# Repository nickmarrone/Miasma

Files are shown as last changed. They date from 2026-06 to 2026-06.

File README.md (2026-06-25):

# Miasma 1.04 Revised

***Note: use the BOM included in this repository.*** Some of the components have been relabelled in this revision so the BOM on SinPhi's website is no longer current.

The changes from version 1.03 are:

1) Updated the footprints and symbols to ones included in KiCAD 5.1.5, or otherwise included the auxillary libraries in the repository.

2) Made the 4QX output no longer inverted and added a jumper pin on the back that allows you to switch between (non-inverted) summing and 4QX modes.

3) Added diodes and jumper pins between the cycle gate input and trigger switch for each side. This allows you to choose whether applying a gate to the cycle input will cause it to start cycling automatically (jumper on) or require a trigger to start cycling (jumper off).

4) Fixed the EOC2 output from not being grounded.

5) Small tweaks such as adjusting track spacing, etc.

To do: the resistor in the feedback loop of the 4QX output amp (R67) should be shorted (solder bridge), not 220k. The purpose is to make this output stage a unity gain buffer instead of an amplifier; the 220k will cause the output to clip before the signal peak is reached. If you aren't using the 4QX feature then this is irrelevant.

# 1.04 Revision

Improve silkscreen placement of component labels for legibility. Upgrade kicad project files to v10.

# Acknowledgements

Original Miasma board by Sin Phi http://www.sinphi.com/synths/miasma/miasma.html, based on the Befaco Rampage http://www.befaco.org/rampage-2/. 4QX and diode mods inspired by Mcop http://www.mcop.co.uk/diy/mods-and-stripboard-layouts/miasma-function-generator-modifications/.

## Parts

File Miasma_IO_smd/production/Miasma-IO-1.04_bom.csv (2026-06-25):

Designator | Footprint | Quantity | Value | LCSC Part #
4QX1, CYCLE1, CYCLE2, EOC1, EOC2, EXPCV1, EXPCV2, FALL1, FALL2, FALLCV1, FALLCV2, IN1, IN2, LGTR1, MAX1, MIN1, OUT1, OUT2, RISE1, RISE2, RISECV1, RISECV2, TRIG1, TRIG2 | WQP-PJ301M-12_JACK | 24 | Thonk
BALANCE1 | Potentiometer_Alpha_RD901F-40-00D_Single_Vertical | 1 | 1M
C1, C11, C14, C4 | C_0805_HandSoldering | 4 | 10n
C10, C8 | C_0805_HandSoldering | 2 | 100nF
C12, C2 | C_0805_HandSoldering | 2 | 470n
C13, C3 | C_0805_HandSoldering | 2 | 47n
C6, C9 | C_0805_HandSoldering | 2 | 100n
CYCLESW1, CYCLESW2, RANGESW1, RANGESW2, TRIGGERSW1 | SPDT_Switch_P4.7mm | 5 | SWITCH_INV
D1, D2, D3, D4, D5, D6 | D_SOD-323_HandSoldering | 6 | 1N4148WS
FALLCVPOT1, FALLCVPOT2, FALLPOT1, FALLPOT2, RISECVPOT1, RISECVPOT2, RISEPOT1, RISEPOT2 | Potentiometer_Alpha_RD901F-40-00D_Single_Vertical | 8 | 100k
FALLTRIM1, FALLTRIM2, RISETRIM1, RISETRIM2 | Bourns_3362P | 4 | 100k
LEDF1, LEDF2, LEDR1, LEDR2 | LED-3MM | 4 | LED
P1, P4 | PinHeader_1x12_P2.54mm_Vertical | 2 | CONN_01X12
P2, P3 | PinHeader_1x10_P2.54mm_Vertical | 2 | CONN_01X10
P5, P6 | PinSocket_1x02_P2.54mm_Vertical | 2 | Conn_01x02
Q1, Q2, Q3, Q4 | SOT-23_Handsoldering | 4 | MMBT3904
R1, R27, R3, R33, R4, R53, R54, R56 | R_0805_HandSoldering | 8 | 10k
R10, R11, R12, R2, R21, R22, R38, R42, R46, R49, R51, R55 | R_0805_HandSoldering | 12 | 100k
R13, R35, R45, R6 | R_0805_HandSoldering | 4 | 47k
R14, R15, R16, R23, R24, R25, R26, R30, R31, R32, R34, R39, R40, R41 | R_0805_HandSoldering | 14 | 1k
R17, R36, R47, R57, R7 | R_0805_HandSoldering | 5 | 1M
R18, R37, R48, R8 | R_0805_HandSoldering | 4 | 110k
R19, R20, R43, R44 | R_0805_HandSoldering | 4 | 2k2
R28, R29 | R_0805_HandSoldering | 2 | 4M7
R5, R50, R52, R9 | R_0805_HandSoldering | 4 | 23k7
SHAPE1, SHAPE2 | Potentiometer_Alpha_RD902F-40-00D_Dual_Vertical | 2 | 10K
SYMETRY1, SYMETRY2 | Bourns_3362P | 2 | 10k
U1 | SOIC-14_3.9x8.7mm_P1.27mm | 1 | TL074

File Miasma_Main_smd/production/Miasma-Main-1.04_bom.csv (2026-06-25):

Designator | Footprint | Quantity | Value | LCSC Part #
C1, C2 | 0805 | 2 | 560p
C10, C11, C12, C13, C14, C15, C16, C17, C19, C20, C21, C22, C23, C24, C25, C26, C27, C28, C5, C6 | 0805 | 20 | 100n
C18, C9 | c_elec_6.3x5.8 | 2 | 10u
C29, C30 | 0805 | 2 | 1n
C3, C4 | 0805 | 2 | 100p
C7, C8 | C_Rect_L7.2mm_W4.5mm_P5.00mm_FKS2_FKP2_MKS2_MKP2 | 2 | 2n2 (PP)
D1, D2 | D_SOD-123 | 2 | 1N5819HW
D10, D11, D12, D13, D14, D15, D16, D17, D18, D19, D20, D21, D22, D23, D24, D25, D3, D4, D5, D6, D7, D8, D9 | D_SOD-323_HandSoldering | 23 | 1N4148WS
P1, P3 | PinHeader_1x12_P2.54mm_Vertical | 2 | CONN_01X12
P2, P4 | PinHeader_1x10_P2.54mm_Vertical | 2 | CONN_01X10
P5 | PinHeader_2x05_P2.54mm_Vertical | 1 | CONN_02X05
P6 | MountingHole_2.7mm_M2.5_DIN965_Pad | 1 | CONN_01X01
P7 | PinHeader_1x03_P2.54mm_Vertical | 1 | SUM_or_4QX
Q1, Q2, Q3, Q4 | SOT-23_Handsoldering | 4 | MMBT3904
R1, R2, R40, R41 | 0805 | 4 | 30k
R10, R14, R16, R8 | 0805 | 4 | 3M
R11, R13, R17, R24, R25, R7 | 0805 | 6 | 560k
R12, R26, R27, R28, R29, R30, R31, R32, R33, R34, R35, R46, R47, R48, R49, R50, R51, R52, R53, R54, R55, R56, R57, R6, R60, R78, R79, R83, R90, R91 | 0805 | 30 | 100k
R15, R18, R19, R74, R76, R9 | 0805 | 6 | 1M
R20, R22, R36, R38 | 0805 | 4 | 4k7
R21, R23, R37, R39, R4, R42, R43, R44, R45, R5, R58, R59, R64, R66, R86, R89 | 0805 | 16 | 10k
R3 | 0805 | 1 | 10M
R61, R62, R80, R81 | 0805 | 4 | 110k
R63, R65 | 0805 | 2 | 180k
R67 | 0805 | 1 | 220k
R68, R69, R70, R71 | 0805 | 4 | 2k2
R72, R73 | 0805 | 2 | 470k
R75, R77 | 0805 | 2 | 22k
R82 | 0805 | 1 | 20k
R84, R85, R87, R88 | 0805 | 4 | 1k
T1, T3 | TSOT-23-6_HandSoldering | 2 | BCM857DS
T2, T4 | TSOT-23-6_HandSoldering | 2 | BCM847DS
U1, U2, U3, U4, U5, U6, U7, U8 | SOIC-14_3.9x8.7mm_P1.27mm | 8 | TL074
U9 | SOIC-8_3.9x4.9mm_P1.27mm | 1 | AD633

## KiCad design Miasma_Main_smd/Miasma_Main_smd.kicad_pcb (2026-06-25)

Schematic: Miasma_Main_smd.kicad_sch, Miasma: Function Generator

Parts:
C1, C2: 560p; C_0805_2012Metric_Pad1.15x1.40mm_HandSolder
C3, C4: 100p; C_0805_2012Metric_Pad1.15x1.40mm_HandSolder
C5, C6, C10, C11, C12, C13, C14, C15, C16, C17, C19, C20, C21, C22, C23, C24, C25, C26, C27, C28: 100n; C_0805_2012Metric_Pad1.15x1.40mm_HandSolder
C9, C18: 10u; c_elec_6.3x5.8
C29, C30: 1n; C_0805_2012Metric_Pad1.15x1.40mm_HandSolder
D1, D2: 1N5819HW; D_SOD-123
D3, D4, D5, D6, D7, D8, D9, D10, D11, D12, D13, D14, D15, D16, D17, D18, D19, D20, D21, D22, D23, D24, D25: 1N4148WS; D_SOD-323_HandSoldering
P1, P3: CONN_01X12; PinHeader_1x12_P2.54mm_Vertical
P2, P4: CONN_01X10; PinHeader_1x10_P2.54mm_Vertical
P5: CONN_02X05; PinHeader_2x05_P2.54mm_Vertical
P6: CONN_01X01; MountingHole_2.7mm_M2.5_DIN965_Pad
P7: SUM_or_4QX; PinHeader_1x03_P2.54mm_Vertical
Q1, Q2, Q3, Q4: MMBT3904; SOT-23_Handsoldering
R1, R2, R40, R41: 30k; R_0805_2012Metric_Pad1.15x1.40mm_HandSolder
R3: 10M; R_0805_2012Metric_Pad1.15x1.40mm_HandSolder
R4, R5, R21, R23, R37, R39, R42, R43, R44, R45, R58, R59, R64, R66, R86, R89: 10k; R_0805_2012Metric_Pad1.15x1.40mm_HandSolder
R6, R12, R26, R27, R28, R29, R30, R31, R32, R33, R34, R35, R46, R47, R48, R49, R50, R51, R52, R53, R54, R55, R56, R57, R60, R78, R79, R83, R90, R91: 100k; R_0805_2012Metric_Pad1.15x1.40mm_HandSolder
R7, R11, R13, R17, R24, R25: 560k; R_0805_2012Metric_Pad1.15x1.40mm_HandSolder
R8, R10, R14, R16: 3M; R_0805_2012Metric_Pad1.15x1.40mm_HandSolder
R9, R15, R18, R19, R74, R76: 1M; R_0805_2012Metric_Pad1.15x1.40mm_HandSolder
R20, R22, R36, R38: 4k7; R_0805_2012Metric_Pad1.15x1.40mm_HandSolder
R61, R62, R80, R81: 110k; R_0805_2012Metric_Pad1.15x1.40mm_HandSolder
R63, R65: 180k; R_0805_2012Metric_Pad1.15x1.40mm_HandSolder
R67: 220k; R_0805_2012Metric_Pad1.15x1.40mm_HandSolder
R68, R69, R70, R71: 2k2; R_0805_2012Metric_Pad1.15x1.40mm_HandSolder
R72, R73: 470k; R_0805_2012Metric_Pad1.15x1.40mm_HandSolder
R75, R77: 22k; R_0805_2012Metric_Pad1.15x1.40mm_HandSolder
R82: 20k; R_0805_2012Metric_Pad1.15x1.40mm_HandSolder
R84, R85, R87, R88: 1k; R_0805_2012Metric_Pad1.15x1.40mm_HandSolder
T1, T3: BCM857DS; TSOT-23-6_HandSoldering
T2, T4: BCM847DS; TSOT-23-6_HandSoldering
U1, U2, U3, U4, U5, U6, U7, U8: TL074; SOIC-14_3.9x8.7mm_P1.27mm
U9: AD633; SOIC-8_3.9x4.9mm_P1.27mm

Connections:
4QX: P4.7, R67.2, U8.8
+1.2V: R86.1, R87.2, U3.9 (-), U6.6 (-)
+2.4V: R82.1, R83.2, U3.2 (-), U6.13 (-)
-1.2V: R88.1, R89.2, U3.12 (+), U6.3 (+)
Bal1: P2.2, R2.2, R90.1, U7.3 (+), U7.5 (+), U8.5 (+), U9.1 (Y1)
Bal2: P4.2, R1.2, R3.2, R91.1, U7.10 (+), U7.12 (+), U8.6 (-), U9.7 (X1)
EOC1: D22.1 (K), P2.9
EOC2: D23.1 (K), P4.9
Exp1: P1.10, R61.2
Exp2: P3.10, R62.2
Fall1: D19.1 (K), P1.2, P2.5
Fall2: D21.1 (K), P3.3, P4.5
FallCv1: P1.4, R10.2, R11.2, R27.1, R28.1, U1.2 (-)
FallCv2: P3.5, R16.2, R17.2, R30.1, R31.1, U4.13 (-)
GND: C9.2, C10.1, C11.1, C12.1, C13.1, C14.1, C15.1, C16.1, C17.1, C18.1, C19.2, C20.2, C21.2, C22.2, C23.2, C24.2, C25.2, C26.2, C27.1, C28.2, P1.1, P1.12, P2.8, P3.1, P3.12, P4.8, P5.3, P5.4, P5.5, P5.6, P5.7, P5.8, Q1.2 (E), Q2.2 (E), Q3.2 (E), Q4.2 (E), R24.2, R25.2, R33.2, R35.2, R40.1, R41.1, R52.2, R53.2, R60.1, R68.1, R69.2, R70.1, R71.2, R75.2, R77.2, R83.1, R84.2, R85.2, R87.1, R88.2, T1.2 (B1), T2.2 (B1), T3.2 (B1), T4.2 (B1), U1.3 (+), U1.10 (+), U1.12 (+), U2.3 (+), U2.10 (+), U2.12 (+), U4.3 (+), U4.5 (+), U4.12 (+), U5.3 (+), U5.5 (+), U5.12 (+), U9.2 (Y2), U9.4 (Z), U9.8 (X2)
In1: D10.1 (K), P2.3, R54.1, U2.6 (-)
In2: D11.1 (K), P4.3, R55.1, U5.9 (-)
L>R: D7.1 (K), P2.7
Max: P4.6, R44.2, U8.14
Min: P2.6, R45.2, U8.1
unnamed: C1.1, R26.2, R27.2, R56.1, U1.8
unnamed: C1.2, R56.2, R61.1, U1.9 (-)
unnamed: C2.1, R29.2, R30.2, R57.1, U4.7
unnamed: C2.2, R57.2, R62.1, U4.6 (-)
unnamed: C3.1, R72.2, T1.3 (C2), T2.6 (C1), U2.13 (-)
unnamed: C3.2, R80.2, U2.14, U3.10 (+), U3.13 (-)
unnamed: C4.1, R73.2, T3.3 (C2), T4.6 (C1), U5.2 (-)
unnamed: C4.2, R81.2, U5.1, U6.2 (-), U6.5 (+)
unnamed: C5.1, D16.2 (A), U3.7
unnamed: C5.2, D22.2 (A), R84.1
unnamed: C6.1, D17.2 (A), U6.8
unnamed: C6.2, D23.2 (A), R85.1
unnamed: D1.2 (A), P5.1, P5.2
unnamed: D2.1 (K), P5.9, P5.10
unnamed: D3.1 (K), D4.1 (K), R18.2, U7.6 (-), U7.9 (-), U8.12 (+)
unnamed: D3.2 (A), U7.7
unnamed: D4.2 (A), U7.8
unnamed: D5.1 (K), U7.1
unnamed: D5.2 (A), D6.2 (A), R19.1, U7.2 (-), U7.13 (-), U8.3 (+)
unnamed: D6.1 (K), U7.14
unnamed: D7.2 (A), U8.7
unnamed: D8.1 (K), R42.1
unnamed: D8.2 (A), U3.1
unnamed: D9.1 (K), R43.1
unnamed: D9.2 (A), U6.14
unnamed: D10.2 (A), Q3.3 (C), R36.1, R37.1
unnamed: D11.2 (A), Q4.3 (C), R38.1, R39.1
unnamed: D12.1 (K), R7.2, R46.2, R68.2, T2.5 (B2)
unnamed: D12.2 (A), D13.2 (A), R9.2
unnamed: D13.1 (K), R47.2, R48.2, R69.1, T1.5 (B2)
unnamed: D14.1 (K), R13.2, R49.2, R70.2, T4.5 (B2)
unnamed: D14.2 (A), D15.2 (A), R15.2
unnamed: D15.1 (K), R50.2, R51.2, R71.1, T3.5 (B2)
unnamed: D16.1 (K), R78.2
unnamed: D17.1 (K), R79.2
unnamed: D18.2 (A), U3.14
unnamed: D19.2 (A), U3.8
unnamed: D20.2 (A), U6.1
unnamed: D21.2 (A), U6.7
unnamed: D24.2 (A), R8.1, R10.1
unnamed: D25.2 (A), R14.1, R16.1
unnamed: P7.1, U9.5 (W)
unnamed: P7.2, U8.10 (+)
unnamed: P7.3, R90.2, R91.2
unnamed: Q1.3 (C), R20.2, R21.2
unnamed: Q2.3 (C), R22.2, R23.2
unnamed: Q3.1 (B), R21.1, R33.1, R42.2
unnamed: Q4.1 (B), R23.1, R35.1, R43.2
unnamed: R4.1, R6.1, R47.1, U1.7
unnamed: R5.1, R12.1, R50.1, U4.8
unnamed: R28.2, R48.1, U1.1
unnamed: R31.2, R51.1, U4.14
unnamed: R32.2, R46.1, U1.14
unnamed: R34.2, R49.1, U4.1
unnamed: R40.2, R44.1, U8.13 (-)
unnamed: R41.2, R45.1, U8.2 (-)
unnamed: R52.1, U2.5 (+)
unnamed: R53.1, U5.10 (+)
unnamed: R54.2, R58.1, U2.7
unnamed: R55.2, R59.1, U5.8
unnamed: R58.2, R63.1, R64.1, U2.2 (-)
unnamed: R59.2, R65.1, R66.1, U5.13 (-)
unnamed: R60.2, R67.1, U8.9 (-)
unnamed: R63.2, R72.1, U2.1
unnamed: R65.2, R73.1, U5.14
unnamed: R74.2, R75.1, R78.1, U3.5 (+)
unnamed: R76.2, R77.1, R79.1, U6.10 (+)
unnamed: R80.1, T1.1 (E1), T1.4 (E2), T2.1 (E1), T2.4 (E2)
unnamed: R81.1, T3.1 (E1), T3.4 (E2), T4.1 (E1), T4.4 (E2)
Out1: C29.2, P2.10, R2.1, R64.2, U2.8, U3.3 (+), U3.6 (-); also elsewhere on the board
Out2: C30.2, P4.10, R1.1, R66.2, U5.7, U6.9 (-), U6.12 (+); also elsewhere on the board
Rise1: D18.1 (K), P1.3, P2.4
Rise2: D20.1 (K), P3.2, P4.4
RiseCv1: P1.5, R6.2, R8.2, R26.1, R32.1, U1.13 (-)
RiseCv2: P3.4, R12.2, R14.2, R29.1, R34.1, U4.2 (-)
RngCap1: C29.1, P1.6, T1.6 (C1), T2.3 (C2), U2.9 (-); also elsewhere on the board
RngCap2: C30.1, P3.6, T3.6 (C1), T4.3 (C2), U5.6 (-); also elsewhere on the board
Sym1_1: P1.7, U1.5 (+)
Sym1_2: P3.7, U4.10 (+)
Sym2_1: D24.1 (K), P1.9, R7.1, R9.1, R11.1
Sym2_2: D25.1 (K), P3.9, R13.1, R15.1, R17.1
Sym3_1: P1.8, R4.2, U1.6 (-)
Sym3_2: P3.8, R5.2, U4.9 (-)
Trig: P3.11, Q2.1 (B), R25.1, R39.2
Trig1: P1.11, Q1.1 (B), R24.1, R37.2
VCC: C9.1, C10.2, C11.2, C12.2, C13.2, C14.2, C15.2, C16.2, C17.2, C27.2, D1.1 (K), P2.1, R19.2, R20.1, R22.1, R36.2, R38.2, R74.1, R76.1, R82.2, R86.2, U1.4 (V+), U2.4 (V+), U3.4 (V+), U4.4 (V+), U5.4 (V+), U6.4 (V+), U7.4 (V+), U8.4 (V+), U9.6 (V+)
VEE: C18.2, C19.1, C20.1, C21.1, C22.1, C23.1, C24.1, C25.1, C26.1, C28.1, D2.2 (A), P4.1, R3.1, R18.1, R89.1, U1.11 (V-), U2.11 (V-), U3.11 (V-), U4.11 (V-), U5.11 (V-), U6.11 (V-), U7.11 (V-), U8.11 (V-), U9.3 (V-)

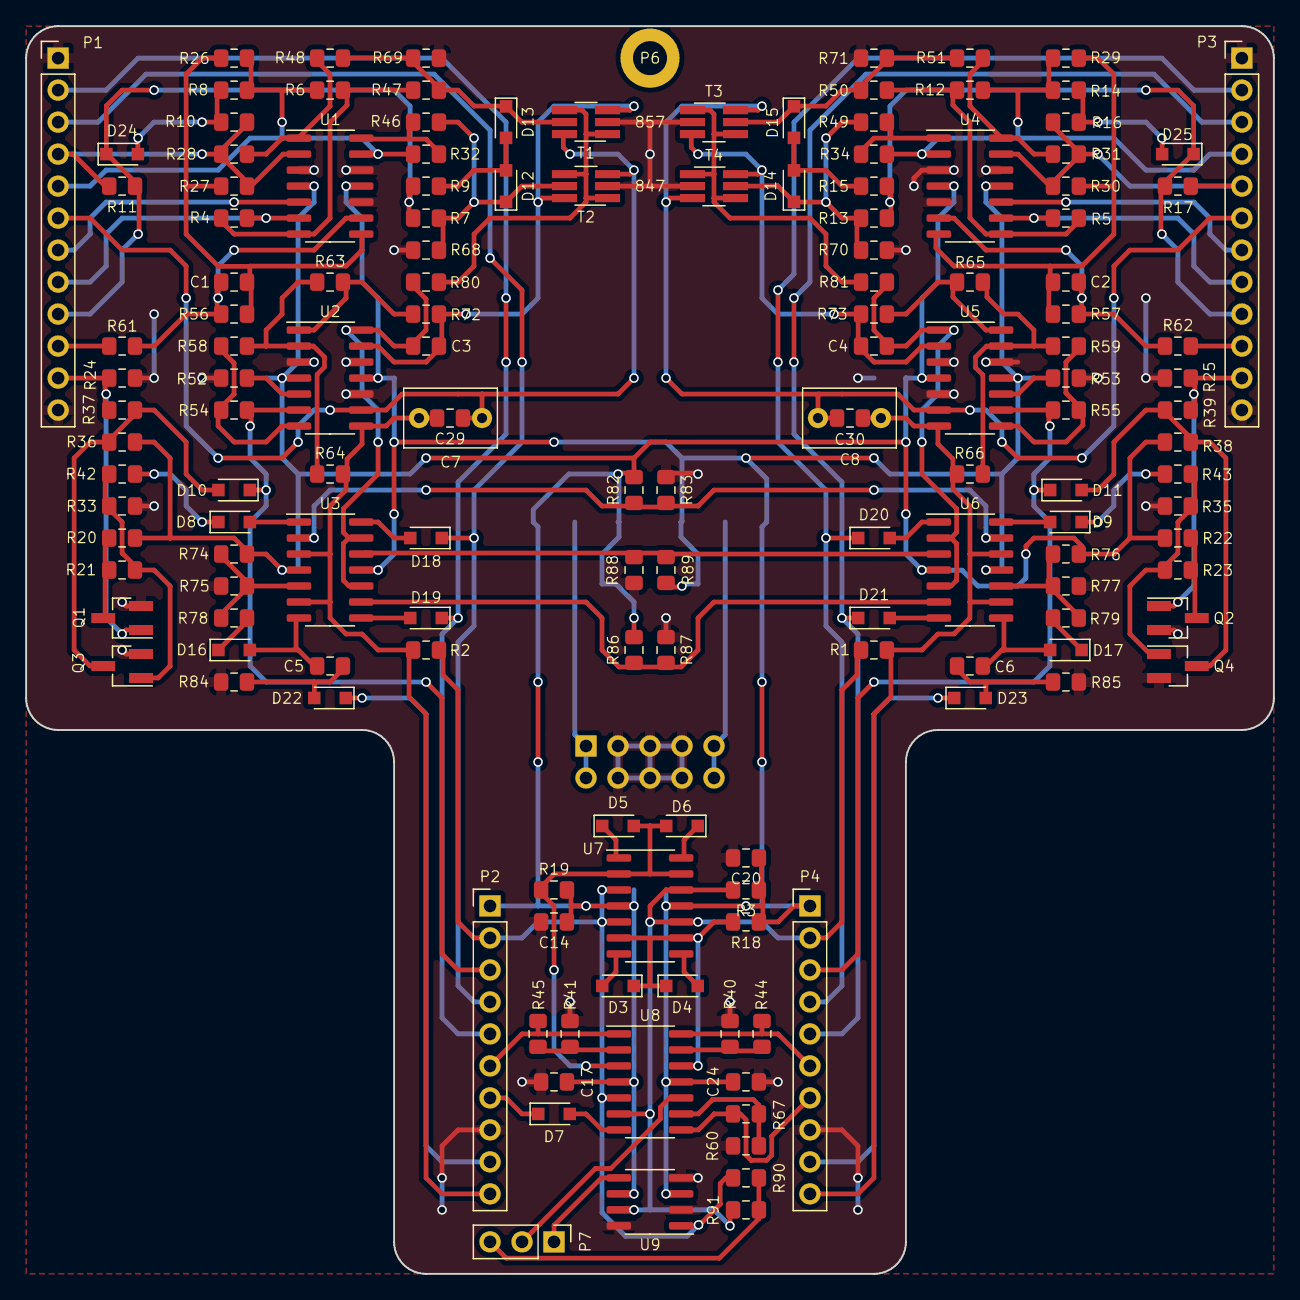
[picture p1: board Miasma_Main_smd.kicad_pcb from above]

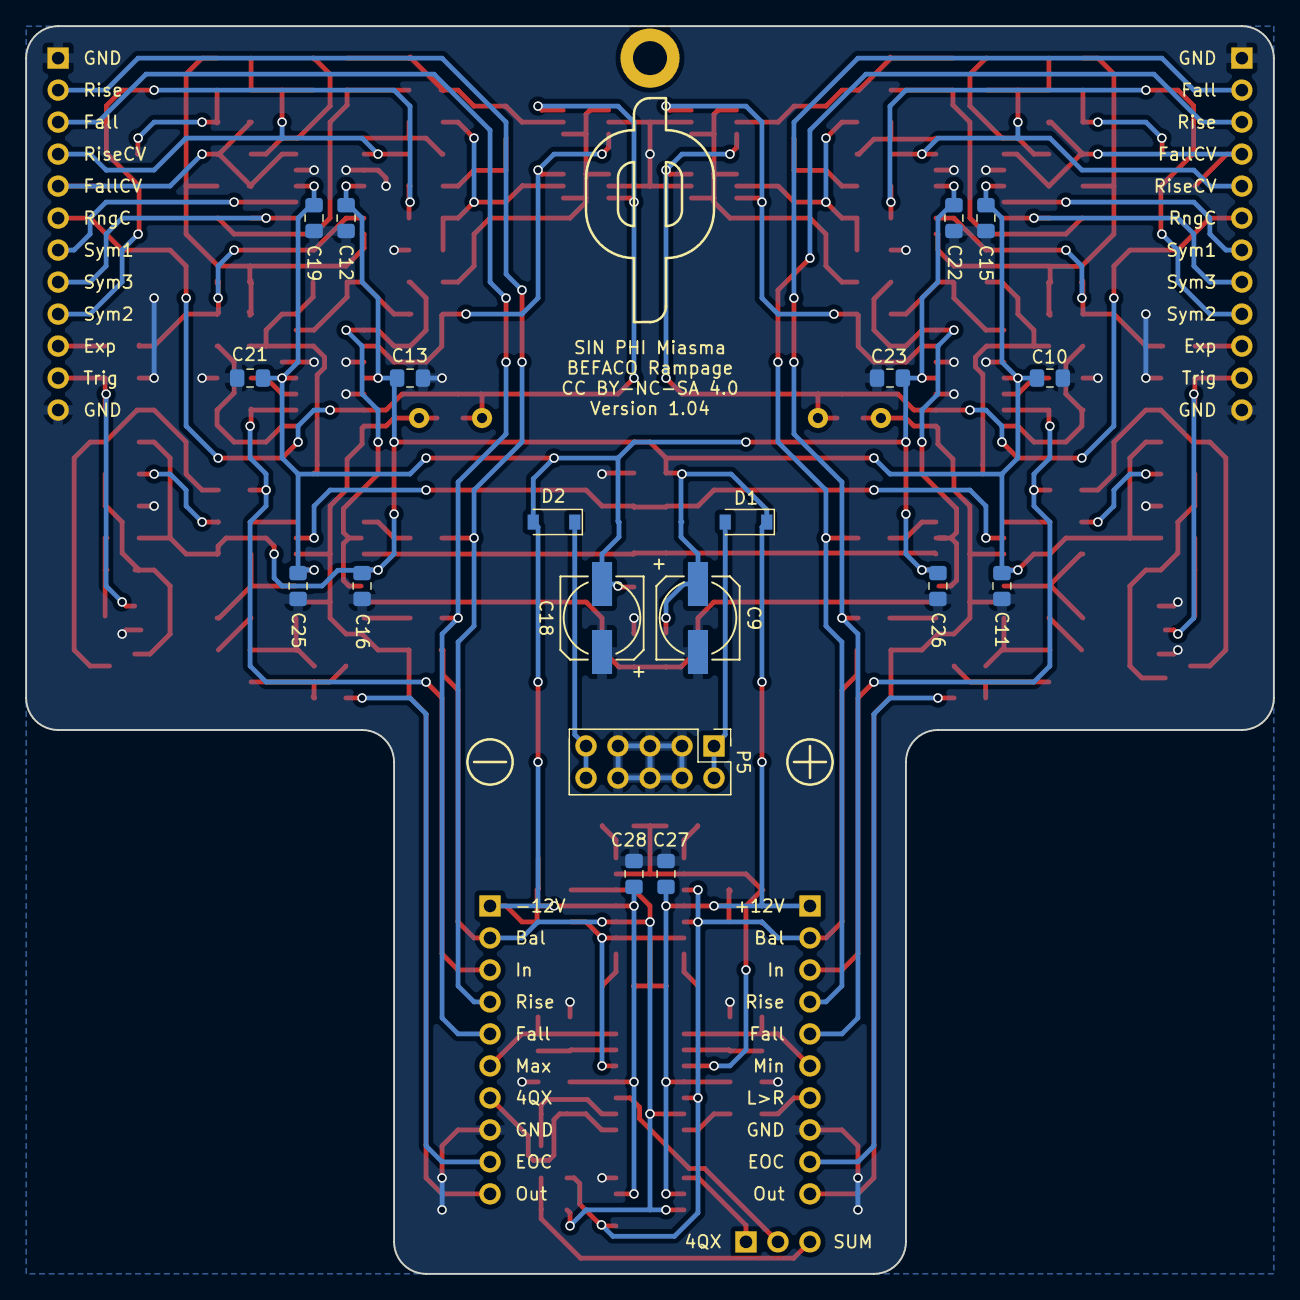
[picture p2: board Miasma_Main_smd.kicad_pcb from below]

Board: 2 copper layers, 99.1 x 99.1 mm, 170 parts (19 on the bottom side), 107 nets.

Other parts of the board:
C7, C8: 2n2 (PP); C_Rect_L7.2mm_W4.5mm_P5.00mm_FKS2_FKP2_MKS2_MKP2

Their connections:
Out1: C7.2; also elsewhere on the board
Out2: C8.2; also elsewhere on the board
RngCap1: C7.1; also elsewhere on the board
RngCap2: C8.1; also elsewhere on the board

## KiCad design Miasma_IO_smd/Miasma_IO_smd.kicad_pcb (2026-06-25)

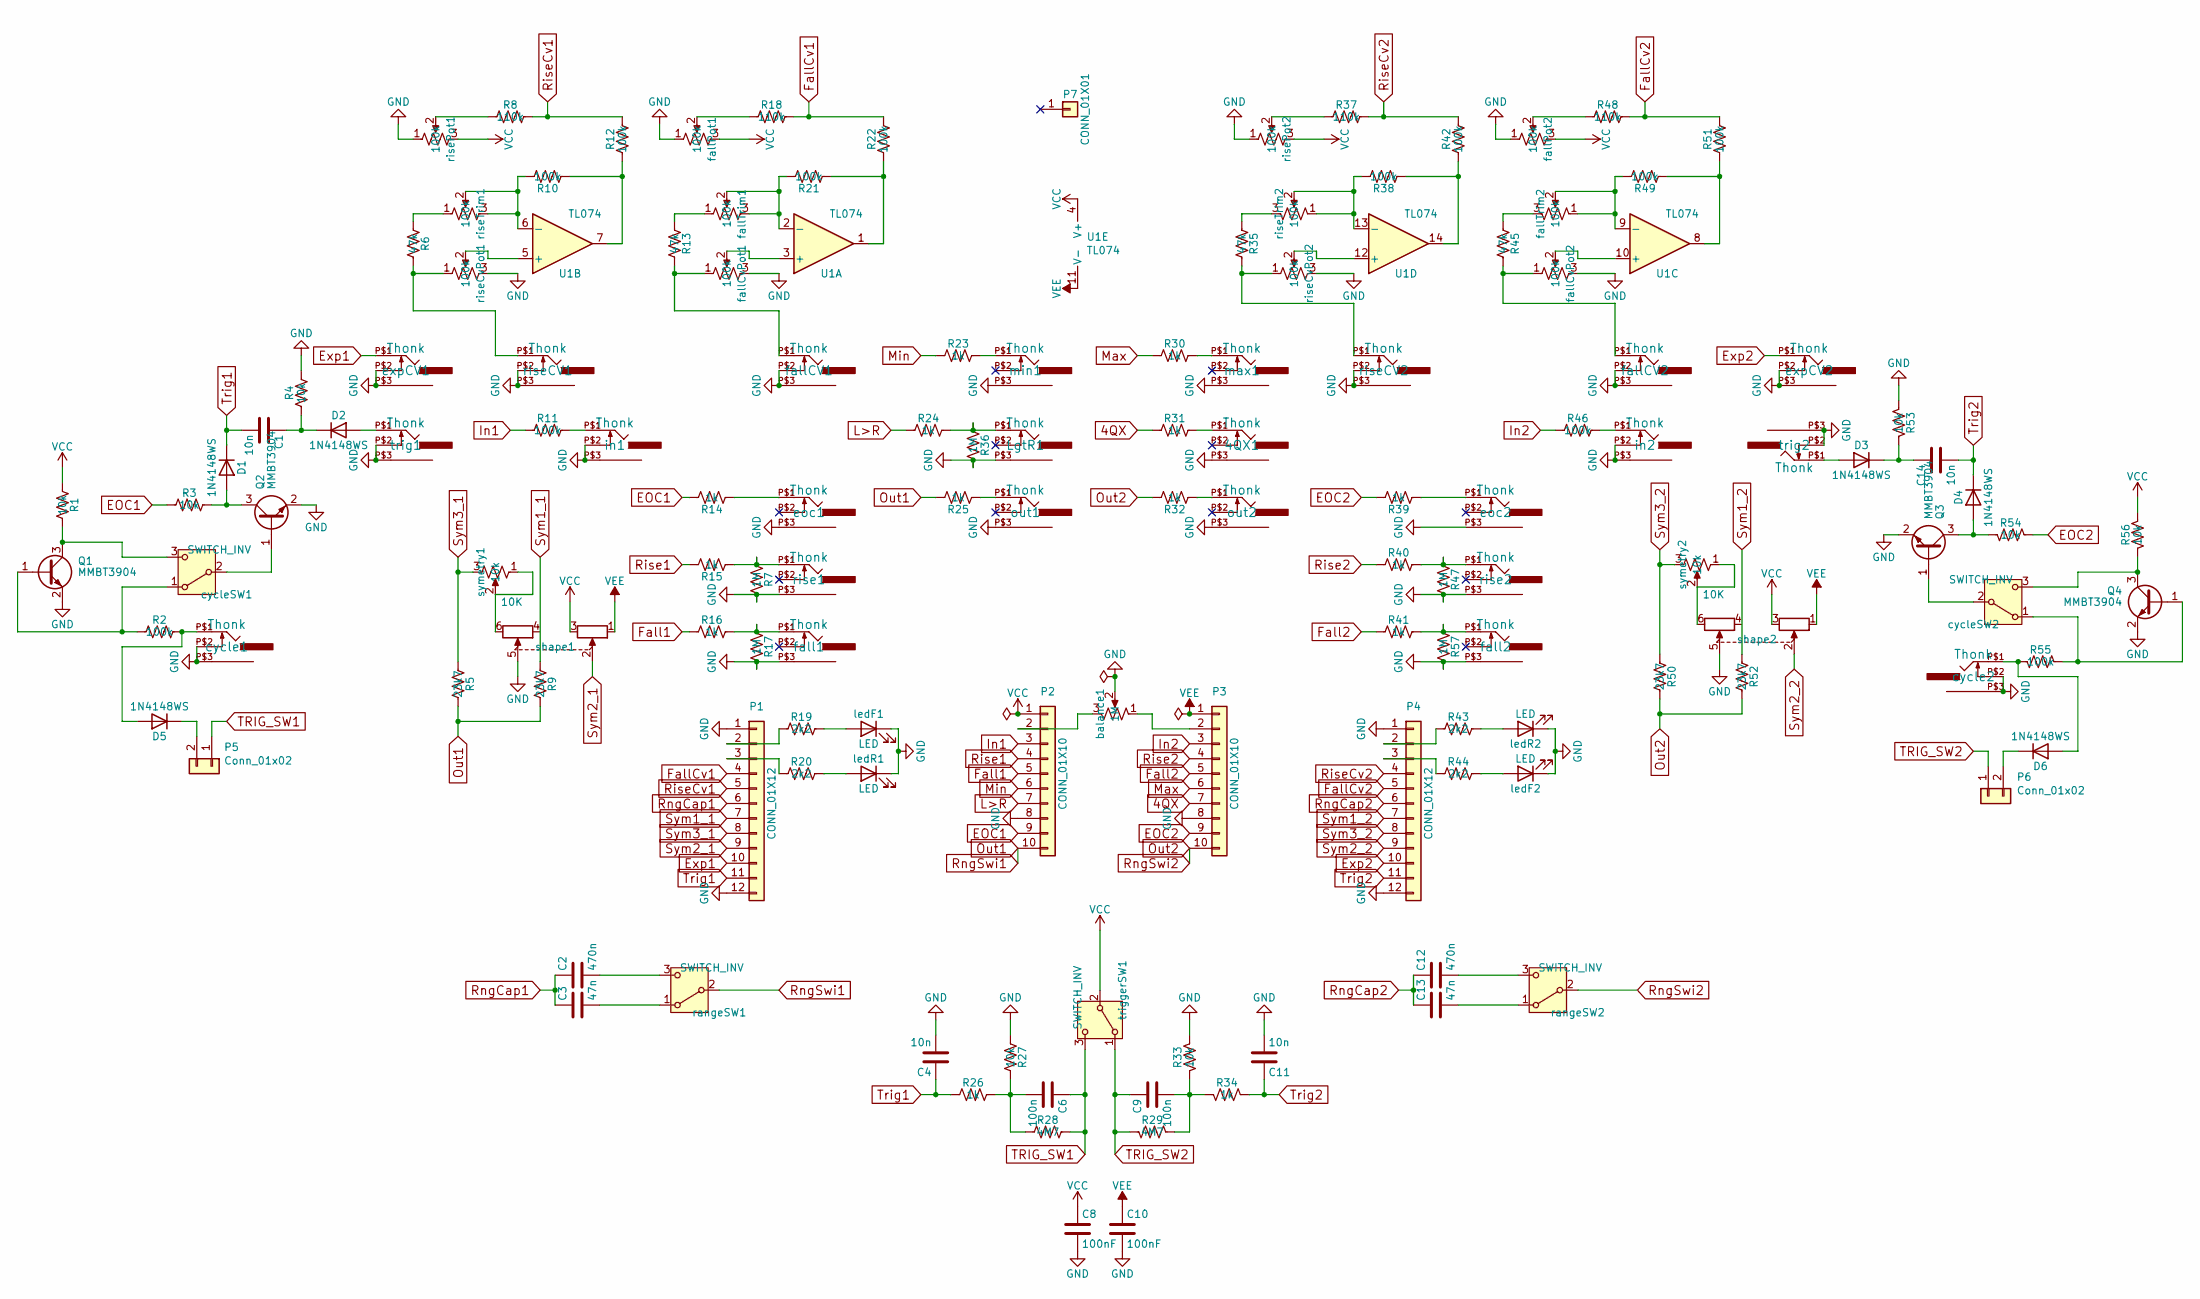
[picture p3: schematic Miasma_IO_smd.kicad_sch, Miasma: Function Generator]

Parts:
4QX1: Thonk; WQP-PJ301M-12_JACK
C1, C4, C11, C14: 10n; C_0805_HandSoldering
C2, C12: 470n; C_0805_HandSoldering
C3, C13: 47n; C_0805_HandSoldering
C6, C9: 100n; C_0805_HandSoldering
C8, C10: 100nF; C_0805_HandSoldering
D1, D2, D3, D4, D5, D6: 1N4148WS; D_SOD-323_HandSoldering
LgtR1: Thonk; WQP-PJ301M-12_JACK
P1, P4: CONN_01X12; PinHeader_1x12_P2.54mm_Vertical
P2, P3: CONN_01X10; PinHeader_1x10_P2.54mm_Vertical
P5, P6: Conn_01x02; PinSocket_1x02_P2.54mm_Vertical
P7: CONN_01X01; MountingHole_2.7mm_M2.5_DIN965_Pad
Q1, Q2, Q3, Q4: MMBT3904; SOT-23_Handsoldering
R1, R3, R4, R27, R33, R53, R54, R56: 10k; R_0805_HandSoldering
R2, R10, R11, R12, R21, R22, R38, R42, R46, R49, R51, R55: 100k; R_0805_HandSoldering
R5, R9, R50, R52: 23k7; R_0805_HandSoldering
R6, R13, R35, R45: 47k; R_0805_HandSoldering
R7, R17, R36, R47, R57: 1M; R_0805_HandSoldering
R8, R18, R37, R48: 110k; R_0805_HandSoldering
R14, R15, R16, R23, R24, R25, R26, R30, R31, R32, R34, R39, R40, R41: 1k; R_0805_HandSoldering
R19, R20, R43, R44: 2k2; R_0805_HandSoldering
R28, R29: 4M7; R_0805_HandSoldering
U1: TL074; SOIC-14_3.9x8.7mm_P1.27mm
balance1: 1M; Potentiometer_Alpha_RD901F-40-00D_Single_Vertical
cycle1, cycle2: Thonk; WQP-PJ301M-12_JACK
cycleSW1, cycleSW2: SWITCH_INV; SPDT_Switch_P4.7mm
eoc1, eoc2: Thonk; WQP-PJ301M-12_JACK
expCV1, expCV2: Thonk; WQP-PJ301M-12_JACK
fall1, fall2: Thonk; WQP-PJ301M-12_JACK
fallCV1, fallCV2: Thonk; WQP-PJ301M-12_JACK
fallCvPot1, fallCvPot2: 100k; Potentiometer_Alpha_RD901F-40-00D_Single_Vertical
fallPot1, fallPot2: 100k; Potentiometer_Alpha_RD901F-40-00D_Single_Vertical
fallTrim1, fallTrim2: 100k; Bourns_3362P
in1, in2: Thonk; WQP-PJ301M-12_JACK
ledF1, ledF2: LED; LED-3MM
ledR1, ledR2: LED; LED-3MM
max1: Thonk; WQP-PJ301M-12_JACK
min1: Thonk; WQP-PJ301M-12_JACK
out1, out2: Thonk; WQP-PJ301M-12_JACK
rangeSW1, rangeSW2: SWITCH_INV; SPDT_Switch_P4.7mm
rise1, rise2: Thonk; WQP-PJ301M-12_JACK
riseCV1, riseCV2: Thonk; WQP-PJ301M-12_JACK
riseCvPot1, riseCvPot2: 100k; Potentiometer_Alpha_RD901F-40-00D_Single_Vertical
risePot1, risePot2: 100k; Potentiometer_Alpha_RD901F-40-00D_Single_Vertical
riseTrim1, riseTrim2: 100k; Bourns_3362P
shape1, shape2: 10K; Potentiometer_Alpha_RD902F-40-00D_Dual_Vertical
symetry1, symetry2: 10k; Bourns_3362P
trig1, trig2: Thonk; WQP-PJ301M-12_JACK
triggerSW1: SWITCH_INV; SPDT_Switch_P4.7mm

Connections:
4QX: P3.7, R31.1
EOC1: P2.9, R3.1, R14.2
EOC2: P3.9, R39.2, R54.1
Exp1: P1.10, expCV1.P$1 (2)
Exp2: P4.10, expCV2.P$1 (2)
Fall1: P2.5, R16.1
Fall2: P3.5, R41.1
FallCv1: P1.4, R18.2, R22.2
FallCv2: P4.5, R48.2, R51.2
GND: 4QX1.P$3 (1), C4.2, C8.2, C10.2, C11.2, LgtR1.P$3 (1), P1.1, P1.12, P2.8, P3.8, P4.1, P4.12, Q1.2 (E), Q2.2 (E), Q3.2 (E), Q4.2 (E), R4.2, R7.2, R17.2, R27.1, R33.1, R36.2, R47.2, R53.2, R57.2, balance1.2, cycle1.P$2 (3), cycle1.P$3 (1), cycle2.P$2 (3), cycle2.P$3 (1), eoc1.P$3 (1), eoc2.P$3 (1), expCV1.P$2 (3), expCV1.P$3 (1), expCV2.P$2 (3), expCV2.P$3 (1), fall1.P$3 (1), fall2.P$3 (1), fallCV1.P$2 (3), fallCV1.P$3 (1), fallCV2.P$2 (3), fallCV2.P$3 (1), fallCvPot1.3, fallCvPot2.3, fallPot1.1, fallPot2.1, in1.P$2 (3), in1.P$3 (1), in2.P$2 (3), in2.P$3 (1), ledF1.1 (K), ledF2.1 (K), ledR1.1 (K), ledR2.1 (K), max1.P$3 (1), min1.P$3 (1), out1.P$3 (1), out2.P$3 (1), rise1.P$3 (1), rise2.P$3 (1), riseCV1.P$2 (3), riseCV1.P$3 (1), riseCV2.P$2 (3), riseCV2.P$3 (1), riseCvPot1.3, riseCvPot2.3, risePot1.1, risePot2.1, shape1.5, shape2.5, trig1.P$2 (3), trig1.P$3 (1), trig2.P$2 (3), trig2.P$3 (1)
In1: P2.3, R11.1
In2: P3.3, R46.1
L>R: P2.7, R24.1
Max: P3.6, R30.1
Min: P2.6, R23.1
unnamed: 4QX1.P$1 (2), R31.2
unnamed: C1.1, D2.1 (K), R4.1
unnamed: C2.2, rangeSW1.3 (C)
unnamed: C3.2, rangeSW1.1 (A)
unnamed: C6.2, R26.2, R27.2, R28.1
unnamed: C9.2, R29.1, R33.2, R34.2
unnamed: C12.2, rangeSW2.3 (C)
unnamed: C13.2, rangeSW2.1 (A)
unnamed: C14.1, D3.1 (K), R53.1
unnamed: D1.2 (A), Q2.3 (C), R3.2
unnamed: D2.2 (A), trig1.P$1 (2)
unnamed: D3.2 (A), trig2.P$1 (2)
unnamed: D4.2 (A), Q3.3 (C), R54.2
unnamed: D5.1 (K), P5.2
unnamed: D5.2 (A), R2.2, cycle1.P$1 (2)
unnamed: D6.1 (K), P6.2
unnamed: D6.2 (A), R55.2, cycle2.P$1 (2)
unnamed: LgtR1.P$1 (2), R24.2, R36.1
unnamed: P1.2, R19.1
unnamed: P1.3, R20.1
unnamed: P2.2, balance1.3
unnamed: P3.2, balance1.1
unnamed: P4.2, R43.1
unnamed: P4.3, R44.1
unnamed: Q1.1 (B), R2.1, cycleSW1.1 (A)
unnamed: Q1.3 (C), R1.2, cycleSW1.3 (C)
unnamed: Q2.1 (B), cycleSW1.2 (B)
unnamed: Q3.1 (B), cycleSW2.2 (B)
unnamed: Q4.1 (B), R55.1, cycleSW2.1 (A)
unnamed: Q4.3 (C), R56.2, cycleSW2.3 (C)
unnamed: R6.1, riseTrim1.1
unnamed: R6.2, riseCV1.P$1 (2), riseCvPot1.1
unnamed: R8.1, risePot1.2
unnamed: R10.1, R12.1, U1.7
unnamed: R10.2, U1.6 (-), riseTrim1.2, riseTrim1.3
unnamed: R11.2, in1.P$1 (2)
unnamed: R13.1, fallTrim1.1
unnamed: R13.2, fallCV1.P$1 (2), fallCvPot1.1
unnamed: R14.1, eoc1.P$1 (2)
unnamed: R7.1, R15.1, rise1.P$1 (2)
unnamed: R16.2, R17.1, fall1.P$1 (2)
unnamed: R18.1, fallPot1.2
unnamed: R19.2, ledF1.2 (A)
unnamed: R20.2, ledR1.2 (A)
unnamed: R21.1, R22.1, U1.1
unnamed: R21.2, U1.2 (-), fallTrim1.2, fallTrim1.3
unnamed: R23.2, min1.P$1 (2)
unnamed: R25.1, out1.P$1 (2)
unnamed: R30.2, max1.P$1 (2)
unnamed: R32.1, out2.P$1 (2)
unnamed: R35.1, riseTrim2.3
unnamed: R35.2, riseCV2.P$1 (2), riseCvPot2.1
unnamed: R37.1, risePot2.2
unnamed: R38.1, R42.1, U1.14
unnamed: R38.2, U1.13 (-), riseTrim2.1, riseTrim2.2
unnamed: R39.1, eoc2.P$1 (2)
unnamed: R40.2, R47.1, rise2.P$1 (2)
unnamed: R41.2, R57.1, fall2.P$1 (2)
unnamed: R43.2, ledR2.2 (A)
unnamed: R44.2, ledF2.2 (A)
unnamed: R45.1, fallTrim2.3
unnamed: R45.2, fallCV2.P$1 (2), fallCvPot2.1
unnamed: R46.2, in2.P$1 (2)
unnamed: R48.1, fallPot2.2
unnamed: R49.1, R51.1, U1.8
unnamed: R49.2, U1.9 (-), fallTrim2.1, fallTrim2.2
unnamed: U1.3 (+), fallCvPot1.2
unnamed: U1.5 (+), riseCvPot1.2
unnamed: U1.10 (+), fallCvPot2.2
unnamed: U1.12 (+), riseCvPot2.2
unnamed: shape1.6, symetry1.1, symetry1.2
unnamed: shape2.6, symetry2.1, symetry2.2
Out1: P2.10, R5.2, R9.2, R25.2, rangeSW1.2 (B)
Out2: P3.10, R32.2, R50.2, R52.2, rangeSW2.2 (B)
Rise1: P2.4, R15.2
Rise2: P3.4, R40.1
RiseCv1: P1.5, R8.2, R12.2
RiseCv2: P4.4, R37.2, R42.2
RngCap1: C2.1, C3.1, P1.6
RngCap2: C12.1, C13.1, P4.6
Sym1_1: P1.7, R9.1, shape1.4
Sym1_2: P4.7, R52.1, shape2.4
Sym2_1: P1.9, shape1.2
Sym2_2: P4.9, shape2.2
Sym3_1: P1.8, R5.1, symetry1.3
Sym3_2: P4.8, R50.1, symetry2.3
TRIG_SW1: C6.1, P5.1, R28.2, triggerSW1.3 (C)
TRIG_SW2: C9.1, P6.1, R29.2, triggerSW1.1 (A)
Trig1: C1.2, C4.1, D1.1 (K), P1.11, R26.1
Trig2: C11.1, C14.2, D4.1 (K), P4.11, R34.1
VCC: C8.1, P2.1, R1.1, R56.1, U1.4 (V+), fallPot1.3, fallPot2.3, risePot1.3, risePot2.3, shape1.3, shape2.3, triggerSW1.2 (B)
VEE: C10.1, P3.1, U1.11 (V-), shape1.1, shape2.1

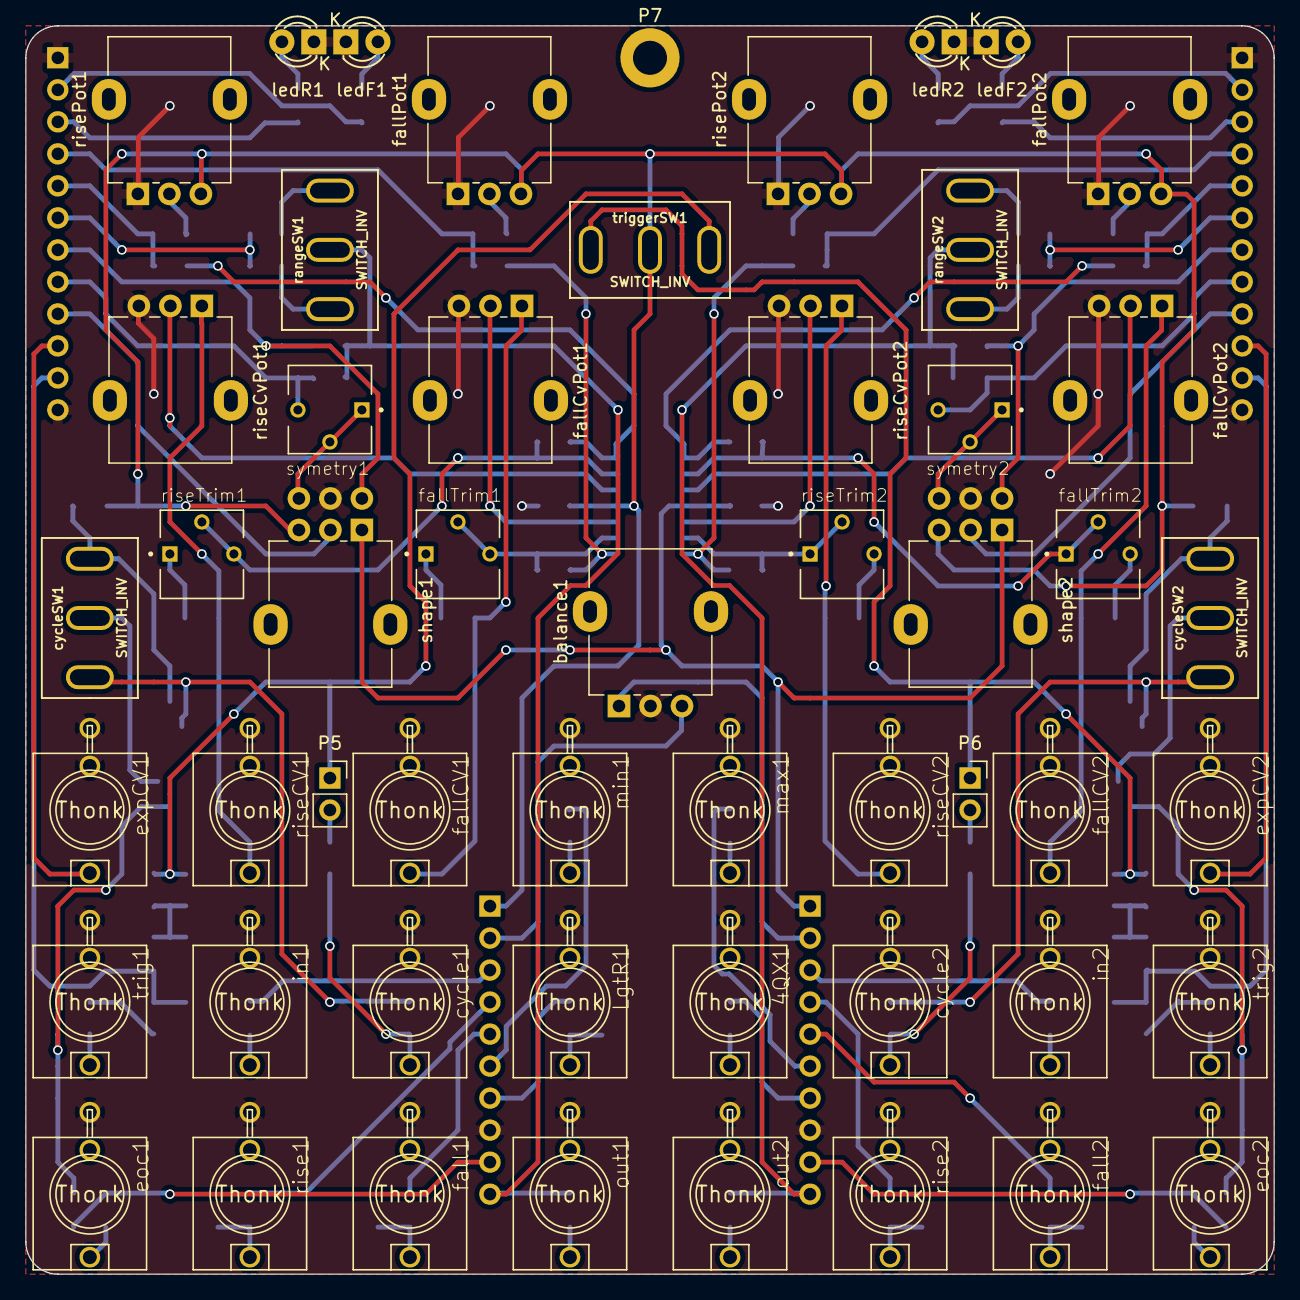
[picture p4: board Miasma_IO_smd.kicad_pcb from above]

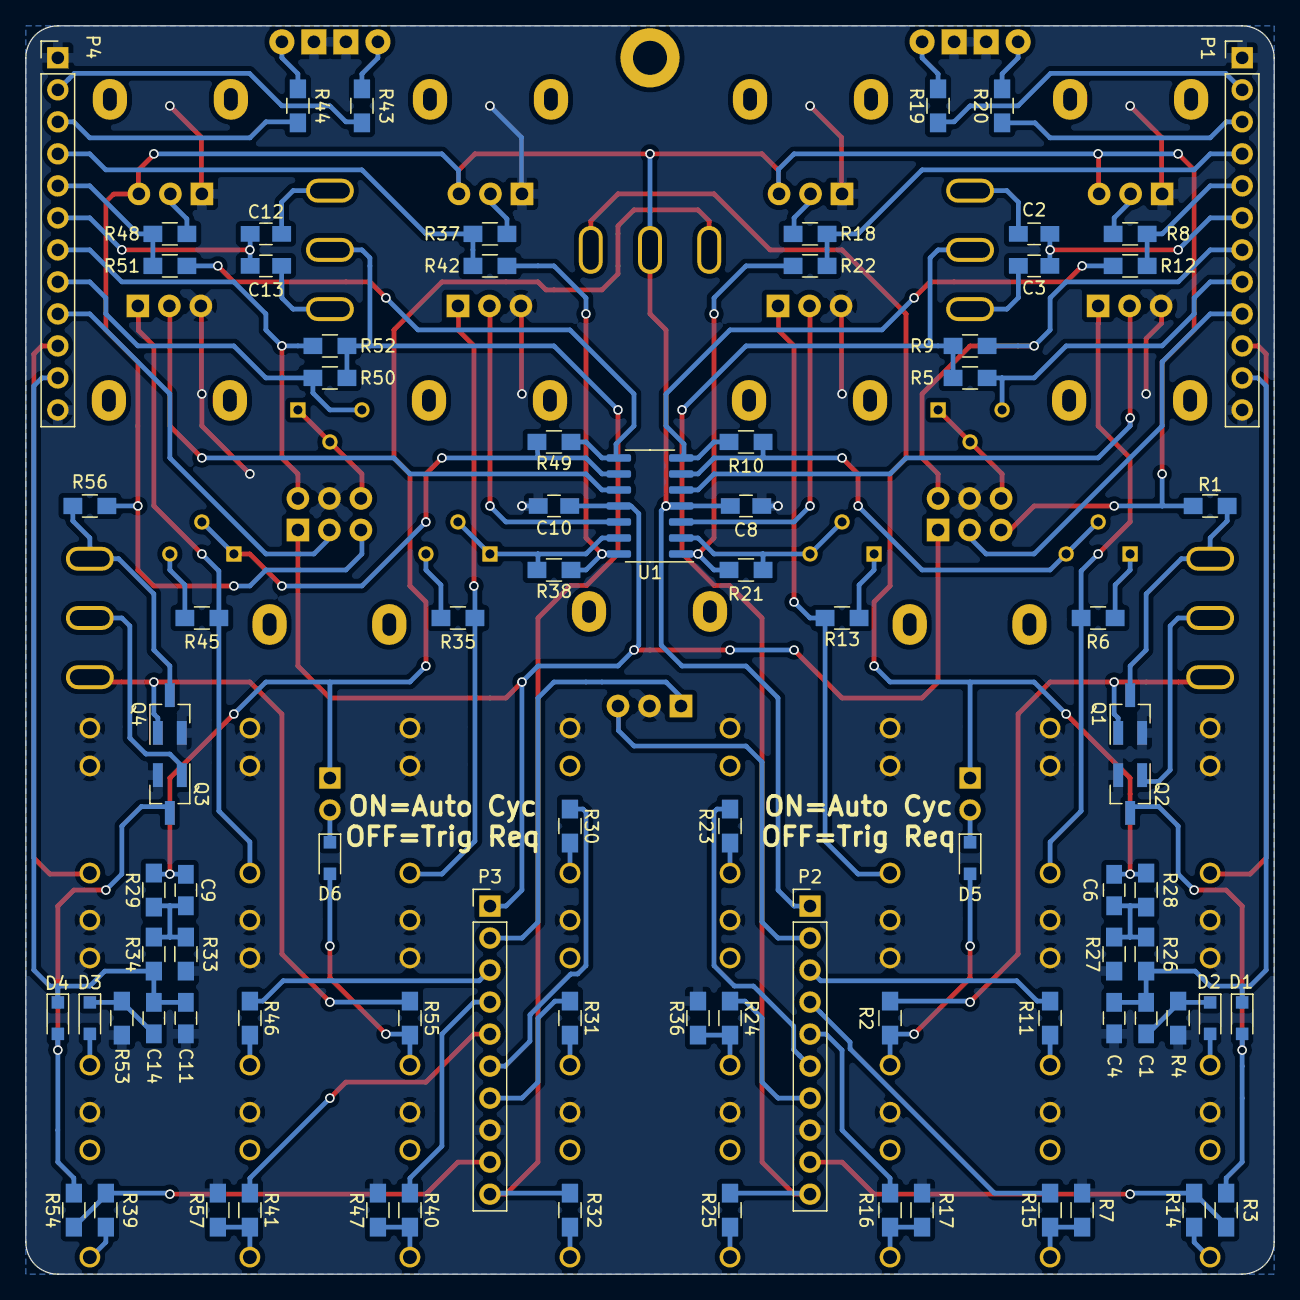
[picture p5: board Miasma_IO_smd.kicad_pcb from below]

Board: 2 copper layers, 99.1 x 99.1 mm, 137 parts (84 on the bottom side), 107 nets.

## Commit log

2026-06-25 Improve silkscreen of Miasma Main board
    Silkscreen was unreadable on PCB because it was placed beneath components
    or on top of other silkscreen. Rearrange silkscreen to make components
    easier to place.
    Kicad project has been saved as a Kicad 10 project now.
    Exported iBOM.
    [Miasma-Main-1.04_bom.csv, Miasma-Main-1.04_designators.csv, Miasma-Main-1.04_positions.csv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]
2026-06-25 Improve silkscreen of Miasma I/O board, fix kicad symbols
    Silkscreen had only a few minor legibility issues.
    Replace some symbols now unavailable in the Kicad 10 library.
    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
    [Miasma-IO-1.04_bom.csv, Miasma-IO-1.04_designators.csv, Miasma-IO-1.04_positions.csv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]

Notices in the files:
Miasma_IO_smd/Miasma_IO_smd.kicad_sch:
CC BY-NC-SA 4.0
